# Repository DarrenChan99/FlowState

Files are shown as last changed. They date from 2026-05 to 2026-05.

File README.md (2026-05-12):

# PlantVision
Plant Vision is a data driven project that aims to use onboard sensors to display useful information and warnings to the user like a predictive watering algorithm and CO2 threshold monitor to help optimally track and water plants and improve productivity through elevated CO2 level warnings, signaling to the user it might be time to step outside.   

# Why?
Recently one of my plants died to unknown factors and I realized that I was guessing when to water and how much sun to give it. At this same time I was getting into C++, microcontrollers, and data based algorithms to build my skills. So after some brainstorming this project perfectly encapsulated my needs while providing a hardware challenge with the custom PCB and an open software ceiling where I could explore data algorithms like the low pass filter and predictive irrigation and experiment with python to better visulize the data and show it on the LCD. 

### Gallery

#### Schematic
Schematic

#### PCB Layout
PCB Layout

#### 3D Render
3D Render

#### CAD View (Front)
CAD Front

#### CAD View (Back)
CAD Back

## BOM
| Component | Description | Part Number | Source | Qty | Notes |
| :--- | :--- | :--- | :--- | :--- | :--- |
| **USB-C** | 16-pin (USB 2.0), Top Mount, Right Angle | **USB4105-GF-A** | DigiKey | 1 | Exact match for HRO footprint. 5A Rated. |
| **CO2 / Temp / Hum** | Sensirion SCD41 Photoacoustic Sensor | **SCD41** | AliExpress | 1 | High accuracy air quality sensing (I2C). |
| **Microcontroller** | ESP32 DevKit V1 (Narrow 30-Pin) | **ESP-WROOM-32** | Amazon | 1 | Dual-core processor with Wi-Fi/Bluetooth. |
| **Voltage Regulator** | 3.3V 800mA LDO (TO-220) | **LD1117V33** | DigiKey | 1 | Converts 5V USB power to 3.3V. |
| **Input Cap (C1)** | 10µF 25V Electrolytic Radial | **860020472003** | DigiKey | 1 | Bulk filter for 5V rail (Würth ATG5). |
| **Output Cap (C2)** | 47µF 16V Electrolytic Radial | **860010372004** | DigiKey | 1 | Stabilizes 3.3V rail (Würth ATG8). |
| **Bypass Cap (C3)** | 100nF 50V X7R Ceramic Radial | **K104K10X7RF5UH5**| DigiKey | 1 | High-frequency noise filter (Vishay). |
| **Resistors** | 5.1k Ohm 1/4W 1% Metal Film | **MFR-25FTE52-5K1**| DigiKey | 2 | Required for SDA/SCL data stability. |
| **Soil Sensor** | Capacitive Moisture Sensor v1.2 | **Generic** | Amazon | 1 | Corrosion-resistant soil tracking. |
| **LCD Touchscreen** | 2.8" or 3.5" TFT SPI Display | **ILI9341** | Amazon | 1 | User interface and data visualization. |
| **Solder Wire** | 0.6mm 63/37 Rosin Core | **Generic** | Amazon | 1 | Precision gauge for USB-C soldering. |
| **Custom PCB** | 1.6mm thick, 2 layer | **Generic** | JLPCB | 1 | Wiring |

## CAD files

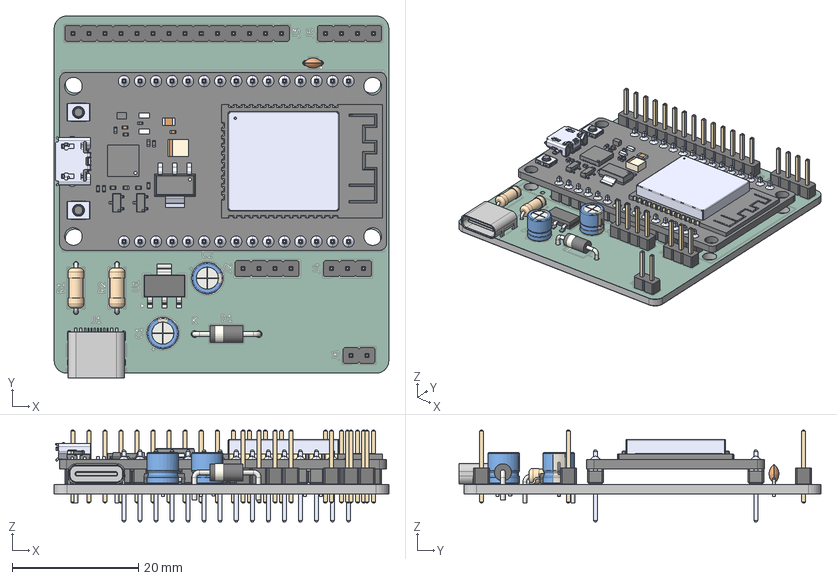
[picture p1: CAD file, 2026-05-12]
FlowState.step
53.0 x 57.3 x 14.5 mm
PinHeader_1x03_P2.54mm_Vertical
PinHeader_1x04_P2.54mm_Vertical x 2
PinHeader_1x02_P2.54mm_Vertical
C_Disc_D3.0mm_W1.6mm_P2.50mm
R_Axial_DIN0207_L6.3mm_D2.5mm_P7.62mm_Horizontal x 2
CP_Radial_D5.0mm_P2.00mm x 2
ESP32-DEVKIT-V1
HRO Type-C 31 M 12
D_DO-41_SOD81_P10.16mm_Horizontal
SOT-223
PinHeader_1x14_P2.54mm_Vertical
FlowState_silkscreen
FlowState_soldermask x 2
FlowState_PCB

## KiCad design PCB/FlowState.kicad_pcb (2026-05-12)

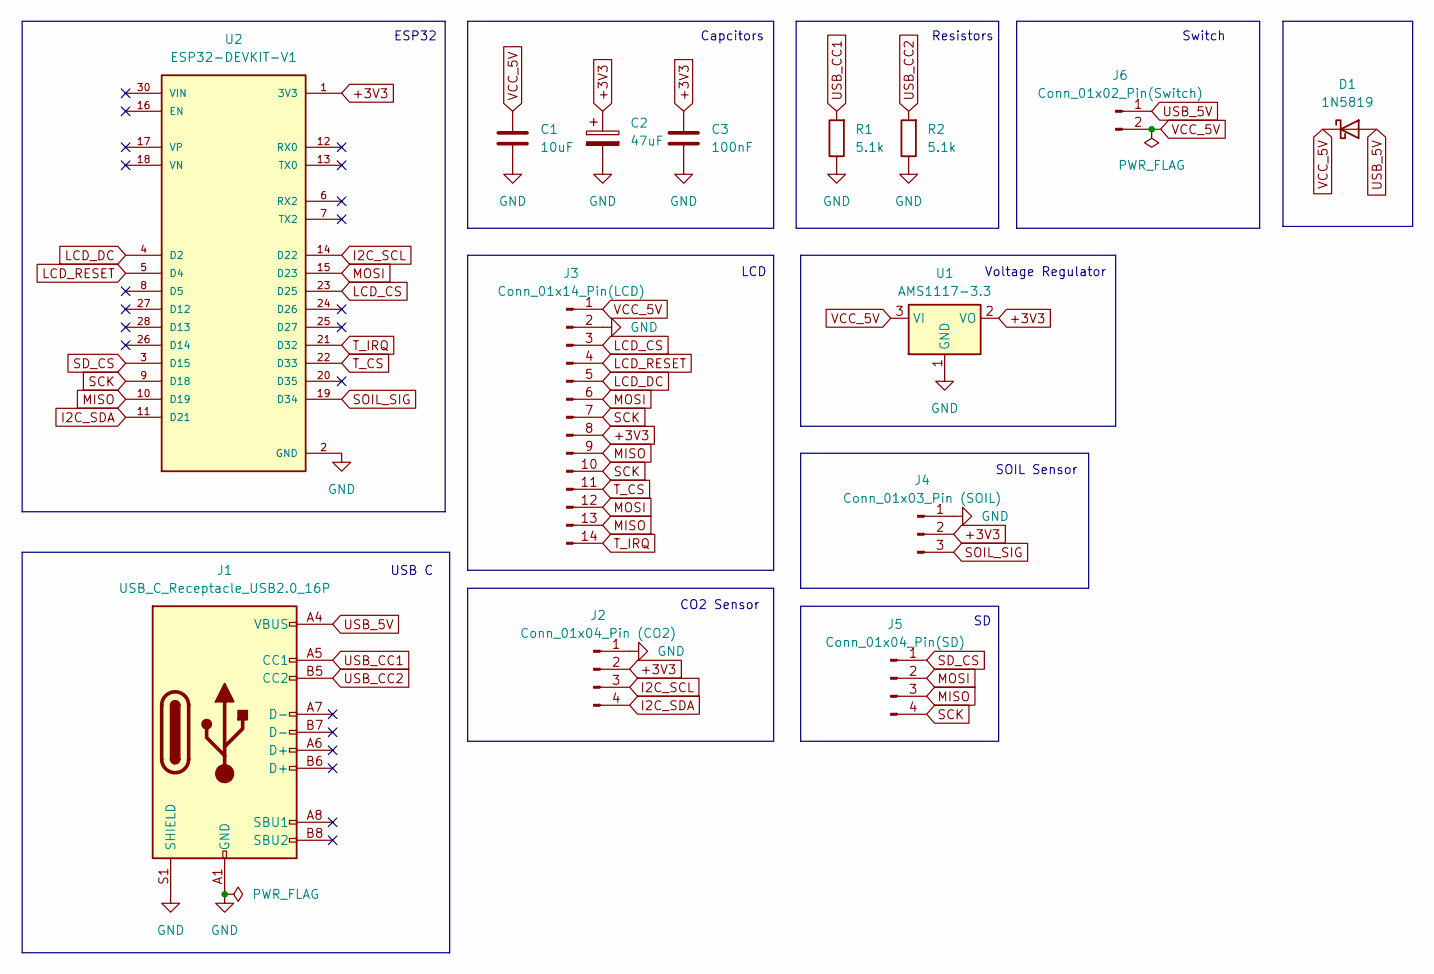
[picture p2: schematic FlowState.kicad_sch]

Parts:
C1: 10uF; CP_Radial_D5.0mm_P2.00mm
C2: 47uF; CP_Radial_D5.0mm_P2.00mm
C3: 100nF; C_Disc_D3.0mm_W1.6mm_P2.50mm
D1: 1N5819; D_DO-41_SOD81_P10.16mm_Horizontal
J1: USB_C_Receptacle_USB2.0_16P; USB_C_Receptacle_HRO_TYPE-C-31-M-12
J2: Conn_01x04_Pin (CO2); PinHeader_1x04_P2.54mm_Vertical
J3: Conn_01x14_Pin(LCD); PinHeader_1x14_P2.54mm_Vertical
J4: Conn_01x03_Pin (SOIL); PinHeader_1x03_P2.54mm_Vertical
J5: Conn_01x04_Pin(SD); PinHeader_1x04_P2.54mm_Vertical
J6: Conn_01x02_Pin(Switch); PinHeader_1x02_P2.54mm_Vertical
R1, R2: 5.1k; R_Axial_DIN0207_L6.3mm_D2.5mm_P7.62mm_Horizontal
U1: AMS1117-3.3; SOT-223-3_TabPin2
U2: ESP32-DEVKIT-V1; MODULE_ESP32_DEVKIT_V1; PARTREV N/A

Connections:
+3V3: C2.1, C3.1, J2.2, J3.8, J4.2, U1.2 (VO), U2.1 (3V3)
GND: C1.2, C2.2, C3.2, J1.A1 (GND), J1.A12 (GND), J1.B1 (GND), J1.B12 (GND), J1.S1 (SHIELD), J2.1, J3.2, J4.1, R1.1, R2.1, U1.1 (GND), U2.2 (GND), U2.29 (GND)
I2C_SCL: J2.3, U2.14 (D22)
I2C_SDA: J2.4, U2.11 (D21)
LCD_CS: J3.3, U2.23 (D25)
LCD_DC: J3.5, U2.4 (D2)
LCD_RESET: J3.4, U2.5 (D4)
MISO: J3.9, J3.13, J5.3, U2.10 (D19)
MOSI: J3.6, J3.12, J5.2, U2.15 (D23)
SCK: J3.7, J3.10, J5.4, U2.9 (D18)
SD_CS: J5.1, U2.3 (D15)
SOIL_SIG: J4.3, U2.19 (D34)
T_CS: J3.11, U2.22 (D33)
T_IRQ: J3.14, U2.21 (D32)
USB_5V: D1.2 (A), J1.A4 (VBUS), J1.A9 (VBUS), J1.B4 (VBUS), J1.B9 (VBUS), J6.1
USB_CC1: J1.A5 (CC1), R1.2
USB_CC2: J1.B5 (CC2), R2.2
VCC_5V: C1.1, D1.1 (K), J3.1, J6.2, U1.3 (VI)

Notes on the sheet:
ESP32
CO2 Sensor
Voltage Regulator
LCD
SOIL Sensor
Switch
Resistors
Capcitors
USB C

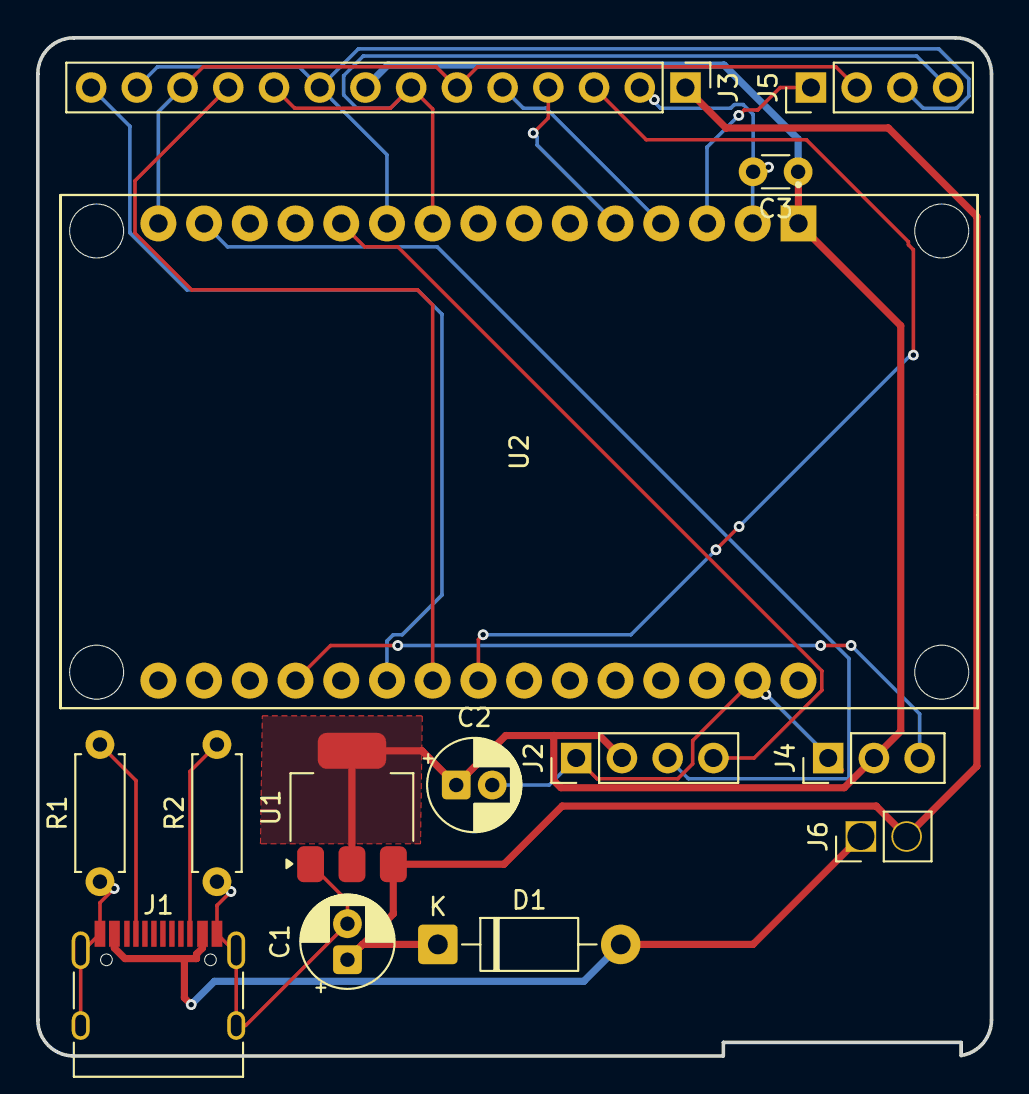
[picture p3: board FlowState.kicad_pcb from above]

Board: 2 copper layers, 53.0 x 56.6 mm, 14 parts (0 on the bottom side), 18 nets.

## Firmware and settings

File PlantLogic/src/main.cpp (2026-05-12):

#include <Arduino.h>
#include <math.h>
#include "logic.h"


LowPass co2Filter(0.1f);    
CarbonProcessor carbonProduction;
PredictiveIrrigatior waterForecast;

unsigned long lastTime = 0;
const float updateRateMs = 2000; 

void setup() {
  Serial.begin(115200);
}

void loop() {
  unsigned long now = millis();

  if (now - lastTime > updateRateMs) {
    // run main logic here on updateRate intervals
  }
}

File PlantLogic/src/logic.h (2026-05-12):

#ifndef LOGIC_H
#define LOGIC_H
#include <math.h>
#include <Arduino.h>

const float KPA = 0.61078f;
const float COEFF_TEMP_A = 17.27f;
const float COEFF_TEMP_B = 237.3f;
const float SOIL_DRY_THRESHOLD = 30.0f; 


class LowPass {
    private: 
      float alpha;
      float previous;
      float initalized = false;
  
    public:
      LowPass(float alpha) : alpha(alpha), previous(0.0f) {}
  
      float update(float input) {
        if (!initalized) {
          previous = input;
          initalized = true;
        }
  
        previous = (alpha * input) + (1 - alpha) * previous;
        return previous;
      }
  
      float getValue() {
        return previous;
      }
  
  };
  
  
  class CarbonProcessor {
    private:
      float last_CO2;
      unsigned long last_time;
      bool initalized = false;
  
    public: 
      float calculate(float current_CO2) {
        if (!initalized) {
          last_CO2 = current_CO2;
          initalized = true;
          return 0.0f;         
        }
  
        unsigned long now = millis();

        float dt = (now - last_time) / 60000.0f;
        float deltaCO2 = current_CO2 - last_CO2;

        last_CO2 = current_CO2;
        last_time = now;
  
        if (dt < 1e-7f) return 0.00f;
        return deltaCO2 /dt;
      }
  };
  
  class PredictiveIrrigatior {
    private:
        float lastMoisture = 0.0f;
        unsigned long lastTimestamp = 0;
        float criticalThreshold;
    
    public:
      PredictiveIrrigatior(float threshold) : criticalThreshold(threshold) {}
  
      float estimateHoursRemaining(float currentMoisture) {
        unsigned long now = millis();
  
        if (lastTimestamp == 0) {
          lastMoisture = currentMoisture;
          lastTimestamp = now;
          return 99.0f;
        }
  
        float dt = (now - lastTimestamp) / 3600000.0f;
  
        if (dt < 1e-7f) return 99.0f;
  
        float drainRate = (lastMoisture - currentMoisture) / dt; 
        lastMoisture = currentMoisture;
        lastTimestamp = now;
  
        if (drainRate < 1e-7f) return 99.0f; // not being watered
        return (currentMoisture - criticalThreshold) / drainRate;
      }
  };
  
  class Utils {
    public:
      static float calculateVPD(float t, float h) {
          float svp = 0.61078f * exp((17.27f * t) / (t + 237.3f));
          float avp = svp * (h / 100.0f);
          return svp - avp;
      }
      
      static float estimateO2Production(float co2PpmDropped, float enclosureVolumeLiters) {
          return co2PpmDropped * enclosureVolumeLiters * 0.727f; 
      }
  
  };
  


#endif

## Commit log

2026-05-06 Fix: Stop tracking ignored files
    [FlowState.kicad_pcb, FlowState.kicad_sch]
2026-05-06 fixed actually
    [FlowState.kicad_pcb, FlowState.kicad_sch]
2026-05-06 fixed ds store to global ignore
    [FlowState.kicad_pcb, FlowState.kicad_sch]
2026-05-06 forgot to add:
    [FlowState.kicad_pcb, FlowState.kicad_sch]
2026-05-06 edits
    rewired LCD to differnt GPIO because that pin has HIGH voltage at startup
    [FlowState.kicad_pcb, FlowState.kicad_sch]
2026-05-07 heatsink
    heatsink good now
    [FlowState.kicad_sch]
2026-05-12 gerber, step, readme
    did lots of stuff
    [FlowState.kicad_pcb, FlowState.kicad_sch, FlowState.step]
2026-05-12 moved and organized
    moved and organized
    [FlowState.kicad_pcb, FlowState.kicad_sch]
2026-05-12 testing
    testing
    [FlowState.kicad_pcb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]
2026-05-12 Update .gitignore to exclude more files
    Added additional Gerber files and VSCode configurations to .gitignore.
2026-05-12 added code
    [FlowState-B_Mask.gbs, FlowState-B_Paste.gbp, FlowState-B_Silkscreen.gbo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]
